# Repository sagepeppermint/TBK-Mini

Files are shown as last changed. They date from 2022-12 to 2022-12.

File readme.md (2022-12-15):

# TBK Mini

---

modded version 
- does not require screws. I used superglue instead. The screws and inserts are difficult to source without resorting to overseas online shopping with lengthy shipping times. 
- you will still require the bottom plate, as the flattened regions of the prior screw mounts are not structurally stable (even with bumpons) when pressing the medial top row buttons.
- modified the pro micro holder to be compatible with the KB2040 (Adafruit).
- see the STL files. Also uploaded the modified blender files for reference. Successfully printed the files at JLCPCB with SLS (3201PA-F) and built a working keyboard.

---

A Dactyl Manuform Mini. Silent and compact, with per-key RGB.




# Sourcing the components

## Electronic components

You will need to order the parts from a shop, and order some PCBs directly from the manufacturer.

Parts list:

| Part name | Amount | Link |
| --- | --- | --- |
| Flexible PCB for the plate | 2 | https://github.com/Bastardkb/TBK-Mini-PCB-plate |
| Flexible PCB for the thumbs | 2 | https://github.com/Bastardkb/TBK-Mini-PCB-thumb-cluster |
| Elite-C | 2 | |
| Elite-C adapter PCB V1.4 | 2 | https://github.com/Bastardkb/Elite-C-holder |
| SOD123 Diodes | 42 | |
| Ribbon cables Flexstrip | 34 | Farnell, Aliexpress |
| Audio jack, SMD | 2 | |
| Button, 4x4x1.5 | 2 | https://www.aliexpress.com/item/1005001304569553.html?spm=a2g0s.9042311.0.0.27424c4dDwgcp7 |

If you want RGB, you will also need:

| Part name | Amount | Format |
| --- | --- | --- |
| SK6812 Mini-E LEDs | 42 | |
| Capacitor, 1uF | 4 | 1206 |
| Resistor, 330Ohms | 4 | 1206 |
| Wires | | 28 AWG recommended, Black, Red, Color |
| Ribbon cables Flexstrip | 6 | |

## Print the case

The STL, STEP and Fusion files are included in this Github.
Feel free to modify them at length. The files are on a non-commercial license, so this is for personal projects only - please do not use those to sell them.

Please find detailed instructions on how to print the case here:
https://docs.bastardkb.com/hc/en-us/articles/360020031180-Print-settings-for-Dactyls

There are also multiple tents types available, in the `files/tents` folder. The recommended one (easiest to print and strongest) is the `alien` one.

## Get a kit from BastardKB

You can also get a full Kit, including case and all PCBs and electronics required on the shop:
https://bastardkb.com/

If you want to print the case yourself, you can also get just the electronics Kit.

# Build guide

Please find detailed build instructions here:
https://docs.bastardkb.com/hc/en-us/articles/4415744748306-Kit-contents-and-required-tools

# Finding help

- Discord: https://bastardkb.com/discord
- Website: https://bastardkb.com/
- Docs: https://docs.bastardkb.com

# Forks

- [With loligagger holder for nice!nanos](https://github.com/nathanielks/TBK-Mini) - reset switch and power switch

# Support me on Patreon

If you like the keyboard, please consider helping me with Patreon: https://www.patreon.com/bastardkb

I post regular updates and hindsight on my work. I work full time on keyboard innovation, and this helps a lot !

# License

This work is licensed under a Creative Commons Attribution-NonCommercial-ShareAlike 4.0 International License.

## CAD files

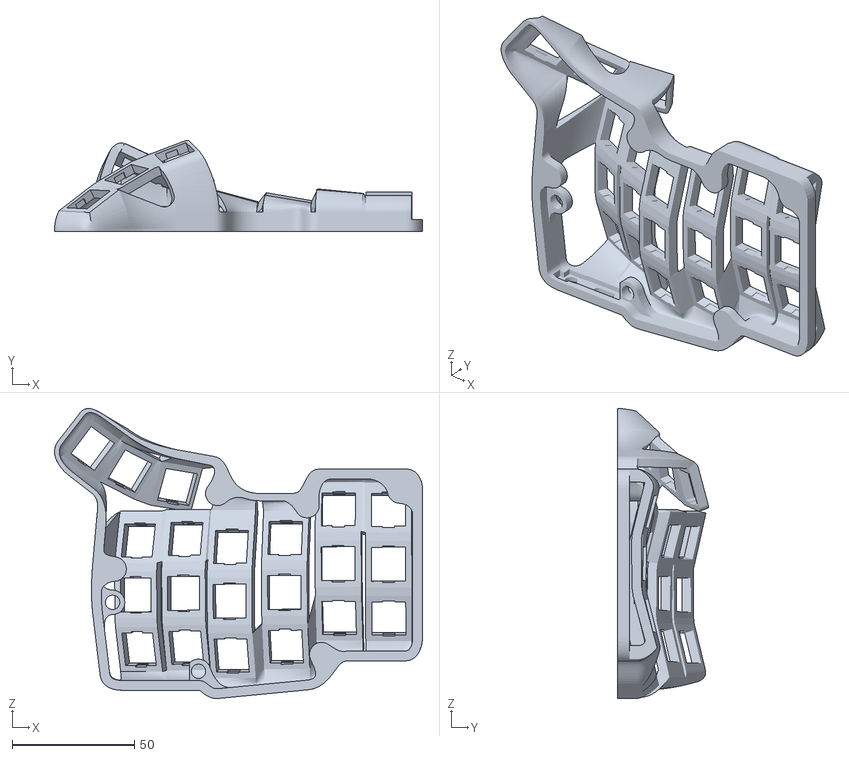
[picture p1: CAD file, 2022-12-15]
top.stl
150.8 x 37.3 x 118.8

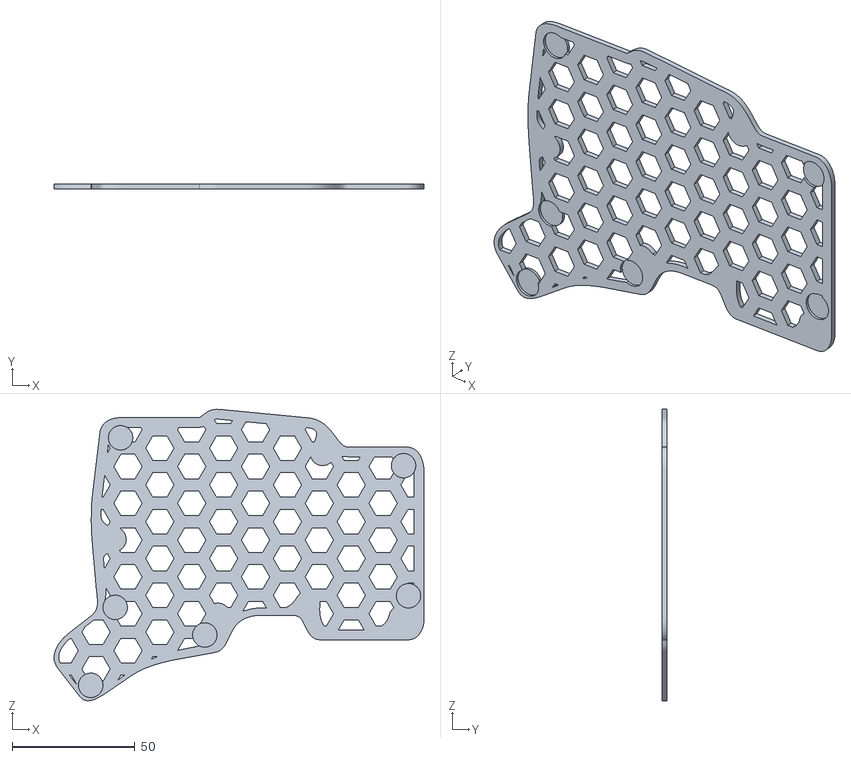
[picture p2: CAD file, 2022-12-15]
bottom mirror.stl
150.8 x 2.00 x 118.8

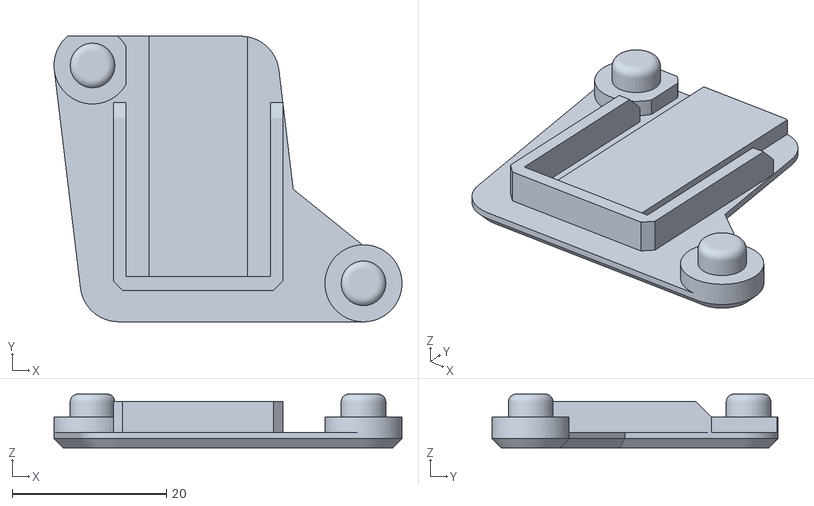
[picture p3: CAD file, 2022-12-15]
pro micro.stl
45.2 x 37.1 x 7.00

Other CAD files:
bottom.stl
pro micro mirror.stl
top mirror.stl
bottom.blend
top.blend
